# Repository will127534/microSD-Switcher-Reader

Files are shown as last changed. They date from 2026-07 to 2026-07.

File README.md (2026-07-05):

# microSD-Switcher-Reader: A simple USB3.0 uSD card reader with a SD card switch for SBCs
_DSC1927

## Introduction
Basically I want some hardware that I can have agents to load images on RPI and test it all from software cmd to have it build/test RPI images for me. There has been some design out there but most of them are USB2.0 which is kinda slow so I wanna build one using USB3 SD reader, and additionally because I'm targeting RPI here, I also whould like to have USB to UART along with a GPIO to power switch on and off the RPI5.

_DSC1934
_DSC1929

So I have the board with GL3224 (USB3 SD card reader) and MCP2221A (USB2 to GPIO/UART/I2C), and because USB3 connector has both USB3 and USB2 signal, I have it connected to the two ICs so no USB hub needed for the two.

The board has been tested with RPI5 and GL3224 has been tested with 100 Megabytes/sec read/write speed. 

Also thanks to https://github.com/NVNTLabs/switch2-SDEX2M2 from NVNTLabs for the microSD card PCB library. (It is a neet MicroSD Express to M.2 adaptor board for Switch2)

## Notes
* Gerber and CPL and BOM file for JLCPCB is under /Gerber
* [Interactive BOM](https://htmlpreview.github.io/?https://github.com/will127534/microSD-Switcher-Reader/blob/main/bom/ibom.html) [(provided by InteractiveHtmlBom)](https://github.com/openscopeproject/InteractiveHtmlBom)   
* Source Code for MCP2221A under /software

## Support
For questions, issues, or suggestions, please open an issue in the [GitHub repository](https://github.com/will127534/microSD-Switcher-Reader/issues)

## Schematic


## PCB


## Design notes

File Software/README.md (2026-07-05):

# SD Switcher Rig

This workspace contains two related tools for a Raspberry Pi SD-switching fixture.

## Tool Overview

`mcp2221_switch.py`

- direct MCP2221 GPIO control
- `GP2`: SD route
  - high: SD connected to the host SD card reader
  - low: SD connected to the target device
- `GP3`: target power/reset switch
  - high for `0.1 s`: short press to boot
  - high for `5.0 s`: long press to hard power off
- `GP0` and `GP1`: left in their current UART LED alternate modes

`initialization.py`

- initialize the MCP2221 to have the default state switch to SD read

## Quick Start

Show live MCP2221 state:

```bash
sudo /home/pi/sd_switcher/mcp2221_switch.py status
```

Route SD to the target device:

```bash
sudo /home/pi/sd_switcher/mcp2221_switch.py sd device
```

Route SD to the host SD card reader:

```bash
sudo /home/pi/sd_switcher/mcp2221_switch.py sd reader
```

Pulse the reset output high for 100 ms:

```bash
sudo /home/pi/sd_switcher/mcp2221_switch.py reset
```

List visible HID devices:

```bash
sudo /home/pi/sd_switcher/mcp2221_switch.py list
```

## Main Files

- `mcp2221_switch.py`: low-level MCP2221 HID controller
- `initialization.py`: programs persistent MCP2221 flash defaults for GP0-GP3

## Persistent MCP2221 Defaults

Program the MCP2221 flash defaults for this fixture:

```bash
sudo /home/pi/sd_switcher/initialization.py apply
```

This sets:

- `GP2` power-up default to GPIO output high
- `GP3` power-up default to GPIO output low
- `GP0` to `LED_URX`
- `GP1` to `LED_UTX`
- UART RX/TX LED polarity to inactive-low / active-high in flash

Inspect the current flash and SRAM GP settings:

```bash
sudo /home/pi/sd_switcher/initialization.py status
```

Reset the MCP2221 so flash chip settings reload:

```bash
sudo /home/pi/sd_switcher/initialization.py reset
```

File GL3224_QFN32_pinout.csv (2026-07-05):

AVDD12 3
AVDD33 8
AVDD33 30
DVDD12 17
DVDD33 16
DVDD33 25
VBUS 15 P
VUHSI 24
SD_VCC 26
GND 27
DP 32
DM 31
TXN 1
TXP 2
RXN 4
RXP 5
RTERM 9
X1 6
X2 7
SD_WP 28
SD_CDZ 29
SD_D1 18
SD_D0 19
SD_CK 20
SD_CM 21
SD_D3 22
SD_D2 23
LED 14
SPI_CS 13
SPI_CK 12
SPI_MISO 10
SPI_MOSI 11

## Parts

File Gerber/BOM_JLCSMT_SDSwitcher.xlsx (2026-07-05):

Comment | Designator | Footprint | JLCPCB Part #（optional）
100nF | C1,C8,C14,C10,C22,C12,C26,C17,C21,C4,C11,C13,C9,C6,C25,C15,C7,C16,C24,C5,C20 | C_0402_1005Metric | C307331
Crystal_CL | C2,C3 | C_0402_1005Metric | C32949
1uF | C19,C18 | C_0402_1005Metric | C52923
25Mhz | Y1 | Crystal_SMD_2520-4Pin_2.5x2.0mm | C7420789
TMUX1574DYYR | U1,U7 | DYY0016A_TEX | C1855769
HD3SS3220IRNHR | IC1 | HD3SS3220IRNHR | C701817
Conn_01x03_MountingPin | J4 | JST_SH_SM03B-SRSS-TB_1x03-1MP_P1.00mm_Horizontal | C160403
Conn_01x04_Shielded | J1 | JST_SH_SM04B-SRSS-TB_1x04-1MP_P1.00mm_Horizontal | C160404
Green | D2,D4 | LED_0603_1608Metric | C12624
Red | D3,D1 | LED_0603_1608Metric | C2286
Blue | D6 | LED_0603_1608Metric | C2288
Orange | D5 | LED_0603_1608Metric | C2287
DM3D-SF | J3 | DM3D-SF | C719027
Conn_01x02_MountingPin | J6 | Molex_PicoBlade_53261-0271_1x02-1MP_P1.25mm_Horizontal | C177225
MCP2221AxML | U2 | QFN-16-1EP_4x4mm_P0.65mm_EP2.5x2.5mm | C637689
GL3224 | U3 | QFN-32-1EP_5x5mm_P0.5mm_EP3.1x3.1mm | C157357
10K | R16,R8,R1,R12,R11,R13,R17 | R_0402_1005Metric | C25744
1K | R4,R18,R3 | R_0402_1005Metric | C11702
900K | R14 | R_0402_1005Metric | C25799
470R | R19,R10,R7,R2,R9,R6 | R_0402_1005Metric | C25117
680R | R5 | R_0402_1005Metric | C25130
200K | R15 | R_0402_1005Metric | C25764
25CSM04xxSN | U4 | SOIC-8_3.9x4.9mm_P1.27mm | C2928893
BSS214NW | Q4,Q3,Q5,Q1,Q2 | SOT-323_SC-70 | C3247496
SiP32431DR3 | U9,U5 | SOT-363_SC-70-6 | C141606
USB_C_Receptacle | J5 | USB_C_Receptacle_Amphenol_12401610E4-2A | C5119948
LP5912-3.3DRV | U6 | WSON-6-1EP_2x2mm_P0.65mm_EP1x1.6mm_ThermalVias | C134121

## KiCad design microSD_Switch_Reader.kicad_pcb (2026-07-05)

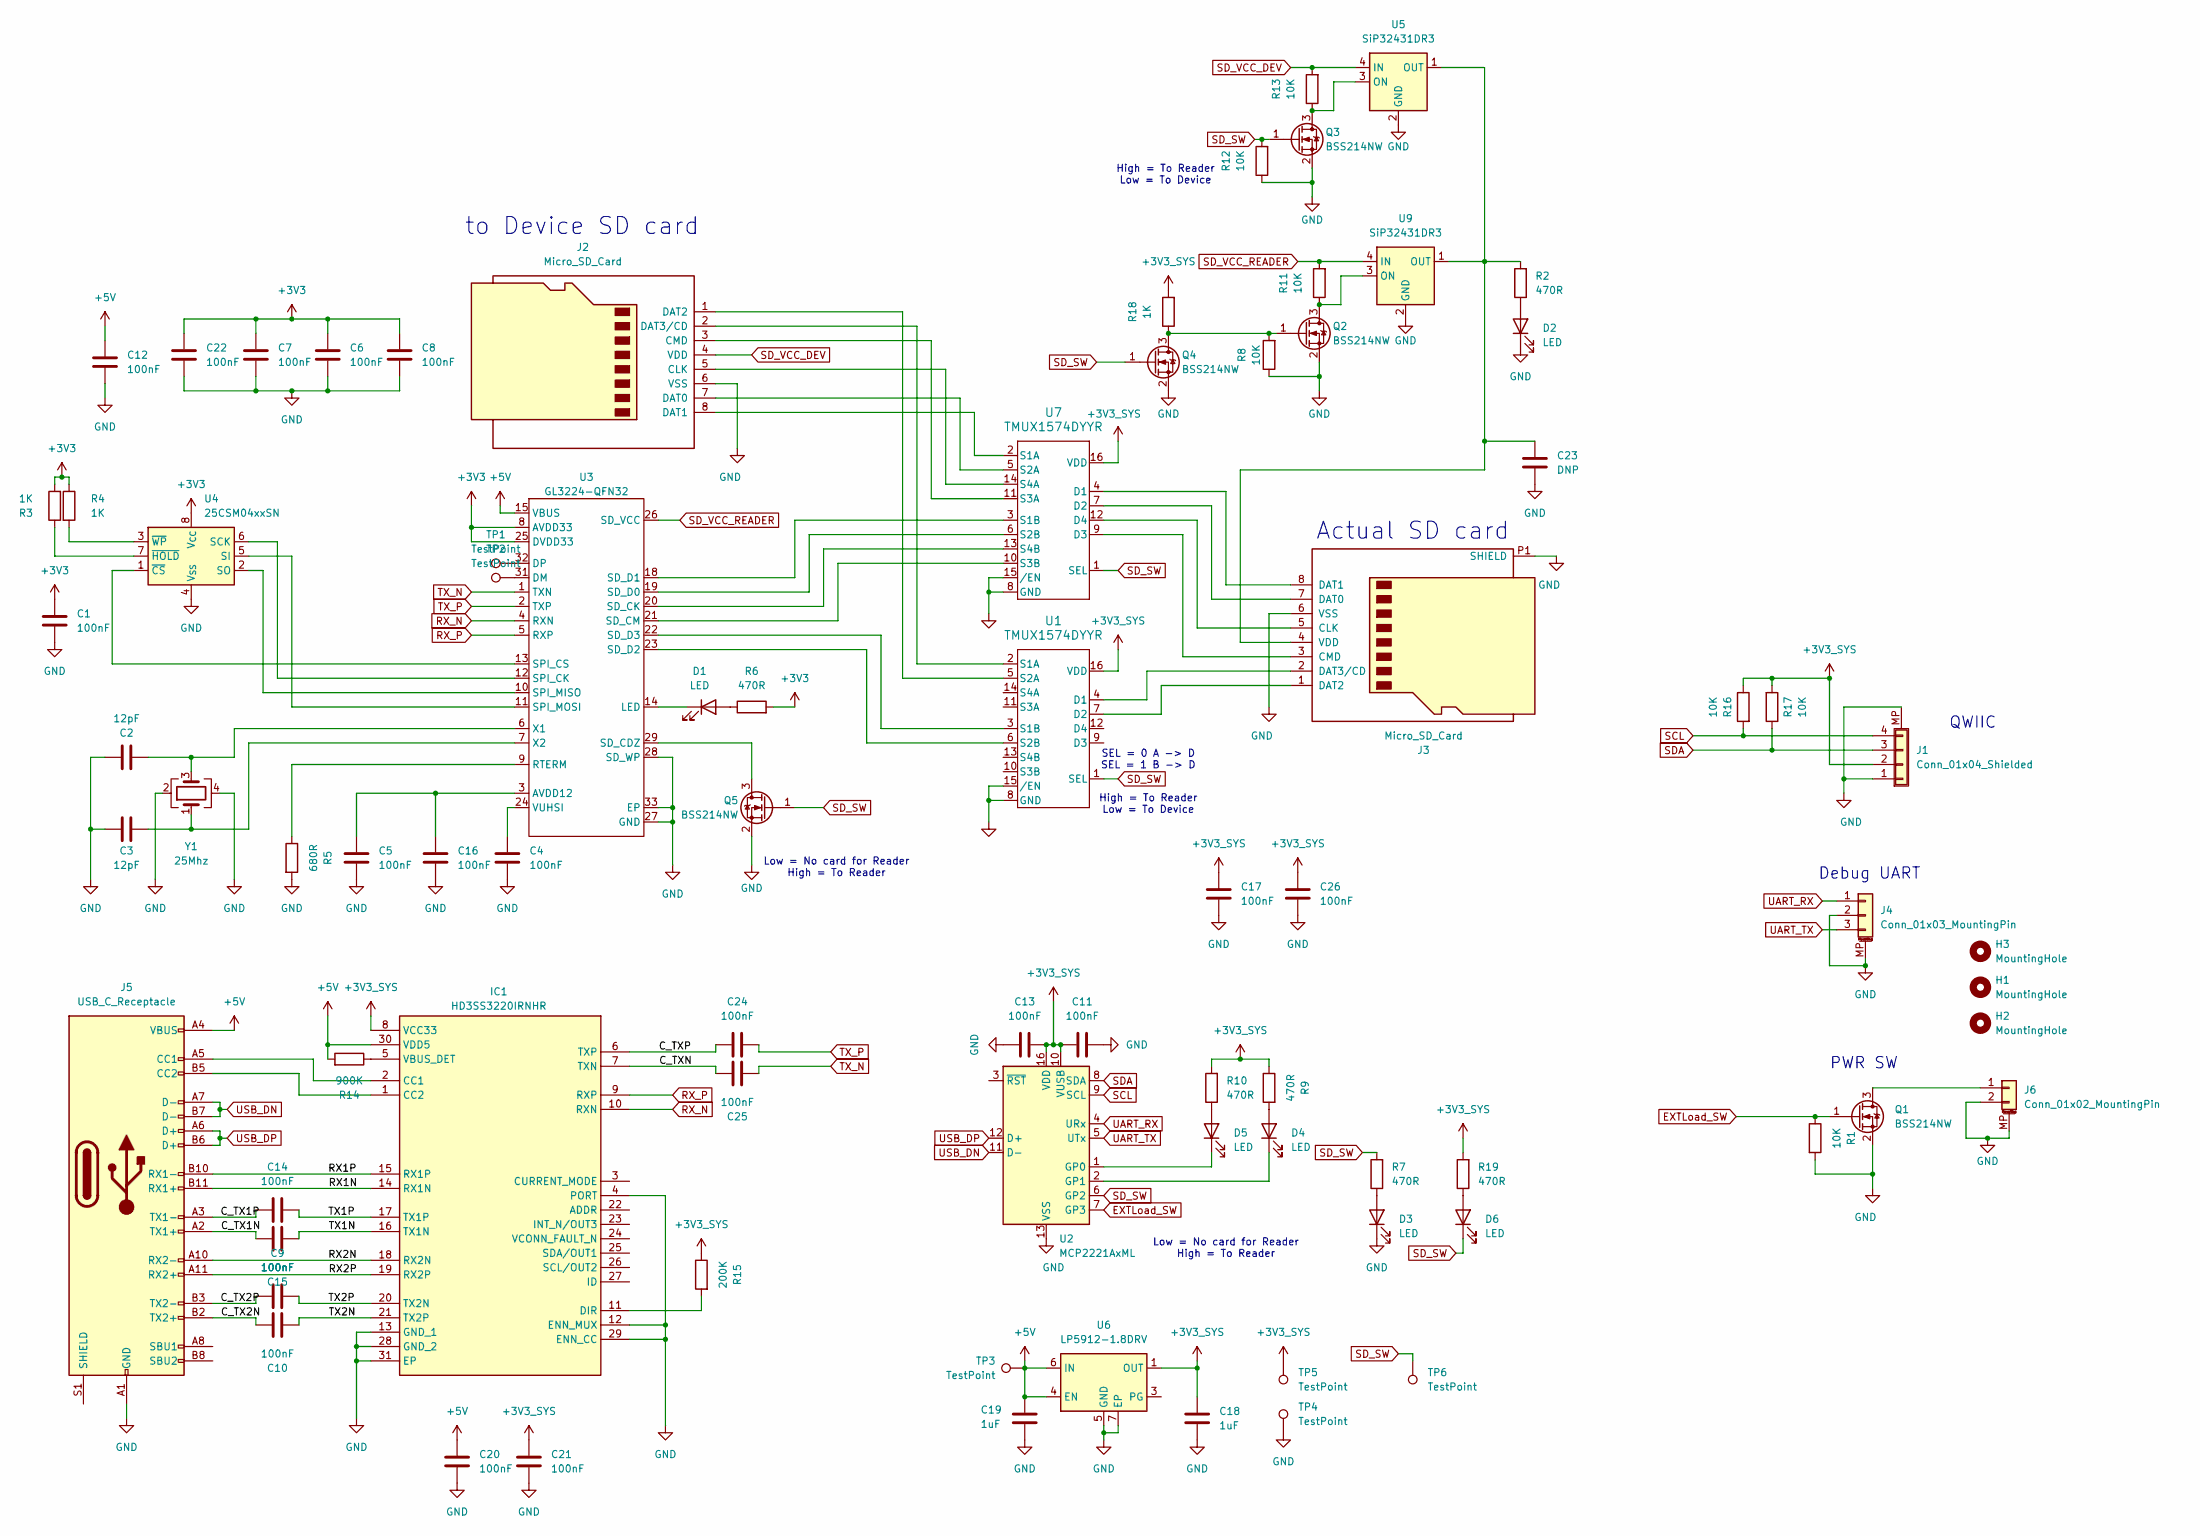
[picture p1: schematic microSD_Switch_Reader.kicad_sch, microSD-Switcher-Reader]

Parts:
C1, C4, C5, C6, C7, C8, C9, C10, C11, C12, C13, C14, C15, C16, C17, C20, C21, C22, C24, C25, C26: 100nF; C_0402_1005Metric
C2, C3: 12pF; C_0402_1005Metric
C18, C19: 1uF; C_0402_1005Metric
C23: DNP; C_0603_1608Metric
D1, D2, D3, D4, D5, D6: LED; LED_0603_1608Metric
H1, H2, H3: MountingHole; MountingHole_2.2mm_M2
IC1: HD3SS3220IRNHR; Mouser Part Number 595-HD3SS3220IRNHR
J1: Conn_01x04_Shielded; JST_SH_SM04B-SRSS-TB_1x04-1MP_P1.00mm_Horizontal
J2: Micro_SD_Card; usdex-male-open_bottom
J3: Micro_SD_Card; microSD_HC_Hirose_DM3D-SF
J4: Conn_01x03_MountingPin; JST_SH_SM03B-SRSS-TB_1x03-1MP_P1.00mm_Horizontal
J5: USB_C_Receptacle; USB_C_Receptacle_Amphenol_12401610E4-2A
J6: Conn_01x02_MountingPin; Molex_PicoBlade_53261-0271_1x02-1MP_P1.25mm_Horizontal
Q1, Q2, Q3, Q4, Q5: BSS214NW; SOT-323_SC-70
R1, R8, R11, R12, R13, R16, R17: 10K; R_0402_1005Metric
R2, R6, R7, R9, R10, R19: 470R; R_0402_1005Metric
R3, R4, R18: 1K; R_0402_1005Metric
R5: 680R; R_0402_1005Metric
R14: 900K; R_0402_1005Metric
R15: 200K; R_0402_1005Metric
TP1, TP2, TP3, TP4, TP5, TP6: TestPoint; TestPoint_Pad_D1.0mm
U1, U7: TMUX1574DYYR; DYY0016A_TEX
U2: MCP2221AxML; QFN-16-1EP_4x4mm_P0.65mm_EP2.5x2.5mm
U3: GL3224-QFN32; QFN-32-1EP_5x5mm_P0.5mm_EP3.1x3.1mm
U4: 25CSM04xxSN; SOIC-8_3.9x4.9mm_P1.27mm
U5, U9: SiP32431DR3; SOT-363_SC-70-6
U6: LP5912-1.8DRV; WSON-6-1EP_2x2mm_P0.65mm_EP1x1.6mm_ThermalVias
Y1: 25Mhz; Crystal_SMD_2520-4Pin_2.5x2.0mm

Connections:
+3V3: C1.1, C6.1, C7.1, C8.1, C22.1, R3.2, R4.1, R6.2, U3.8 (AVDD33), U3.16 (DVDD33), U3.25 (DVDD33), U3.30 (AVDD33), U4.8 (V_{CC})
+3V3_SYS: C11.1, C13.2, C17.1, C18.1, C21.1, C26.1, IC1.8 (VCC33), J1.2, R9.1, R10.2, R15.1, R16.1, R17.2, R18.2, R19.2, TP5.1, U1.16 (VDD), U2.10 (VUSB), U2.16 (VDD), U6.1 (OUT), U7.16 (VDD)
+5V: C12.1, C19.1, C20.1, IC1.30 (VDD5), J5.A4 (VBUS), J5.A9 (VBUS), J5.B4 (VBUS), J5.B9 (VBUS), R14.2, TP3.1, U3.15 (VBUS), U6.4 (EN), U6.6 (IN)
/C_TX1N: C15.2, J5.A2 (TX1+)
/C_TX1P: C14.1, J5.A3 (TX1-)
/C_TX2N: C10.2, J5.B2 (TX2+)
/C_TX2P: C9.1, J5.B3 (TX2-)
/C_TXN: C25.2, IC1.7 (TXN)
/C_TXP: C24.1, IC1.6 (TXP)
/RX1N: IC1.14 (RX1N), J5.B11 (RX1+)
/RX1P: IC1.15 (RX1P), J5.B10 (RX1-)
/RX2N: IC1.18 (RX2N), J5.A10 (RX2-)
/RX2P: IC1.19 (RX2P), J5.A11 (RX2+)
/TX1N: C15.1, IC1.16 (TX1N)
/TX1P: C14.2, IC1.17 (TX1P)
/TX2N: C10.1, IC1.21 (TX2P)
/TX2P: C9.2, IC1.20 (TX2N)
EXTLoad_SW: Q1.1 (G), R1.1, U2.7 (GP3)
GND: C1.2, C2.1, C3.1, C4.2, C5.2, C6.2, C7.2, C8.2, C11.2, C12.2, C13.1, C16.2, C17.2, C18.2, C19.2, C20.2, C21.2, C22.2, C23.2, C26.2, D2.1 (K), D3.1 (K), IC1.4 (PORT), IC1.12 (ENN_MUX), IC1.13 (GND_1), IC1.28 (GND_2), IC1.29 (ENN_CC), IC1.31 (EP), J1.1, J1.MP (Shield), J2.6 (VSS), J3.6 (VSS), J3.P1 (SHIELD), J3.P2 (SHIELD), J3.P3 (SHIELD), J3.P4 (SHIELD), J3.P5 (SHIELD), J4.2, J4.MP (MountPin), J5.A1 (GND), J5.A12 (GND), J5.B1 (GND), J5.B12 (GND), J6.2, J6.MP (MountPin), Q1.2 (S), Q2.2 (S), Q3.2 (S), Q4.2 (S), Q5.2 (S), R1.2, R5.2, R8.1, R12.1, TP4.1, U1.8 (GND), U1.15 (/EN), U2.13 (VSS), U3.27 (GND), U3.28 (SD_WP), U3.33 (EP), U4.4 (V_{SS}), U5.2 (GND), U5.5 (GND), U6.5 (GND), U6.7 (EP), U7.8 (GND), U7.15 (/EN), U9.2 (GND), U9.5 (GND), Y1.2, Y1.4
unnamed: D1.2 (A), R6.1
unnamed: D1.1 (K), U3.14 (LED)
unnamed: D2.2 (A), R2.1
unnamed: D3.2 (A), R7.1
unnamed: D4.2 (A), R9.2
unnamed: D4.1 (K), U2.2 (GP1)
unnamed: D5.2 (A), R10.1
unnamed: D5.1 (K), U2.1 (GP0)
unnamed: D6.2 (A), R19.1
unnamed: IC1.2 (CC1), J5.A5 (CC1)
unnamed: IC1.1 (CC2), J5.B5 (CC2)
unnamed: IC1.11 (DIR), R15.2
unnamed: IC1.5 (VBUS_DET), R14.1
unnamed: J2.5 (CLK), U7.14 (S4A)
unnamed: J2.3 (CMD), U7.11 (S3A)
unnamed: J2.7 (DAT0), U7.5 (S2A)
unnamed: J2.8 (DAT1), U7.2 (S1A)
unnamed: J2.1 (DAT2), U1.5 (S2A)
unnamed: J2.2 (DAT3/CD), U1.2 (S1A)
unnamed: J3.5 (CLK), U7.12 (D4)
unnamed: J3.3 (CMD), U7.9 (D3)
unnamed: J3.7 (DAT0), U7.7 (D2)
unnamed: J3.8 (DAT1), U7.4 (D1)
unnamed: J3.1 (DAT2), U1.7 (D2)
unnamed: J3.2 (DAT3/CD), U1.4 (D1)
unnamed: C23.1, J3.4 (VDD), R2.2, U5.1 (OUT), U9.1 (OUT)
unnamed: J6.1, Q1.3 (D)
unnamed: Q2.3 (D), R11.1, U9.3 (ON)
unnamed: Q2.1 (G), Q4.3 (D), R8.2, R18.1
unnamed: Q3.3 (D), R13.1, U5.3 (ON)
unnamed: Q5.3 (D), U3.29 (SD_CDZ)
unnamed: U1.3 (S1B), U3.22 (SD_D3)
unnamed: U1.6 (S2B), U3.23 (SD_D2)
unnamed: C5.1, C16.1, U3.3 (AVDD12), U3.17 (DVDD12)
unnamed: TP2.1, U3.31 (DM)
unnamed: TP1.1, U3.32 (DP)
unnamed: R5.1, U3.9 (RTERM)
unnamed: U3.20 (SD_CK), U7.13 (S4B)
unnamed: U3.21 (SD_CM), U7.10 (S3B)
unnamed: U3.19 (SD_D0), U7.6 (S2B)
unnamed: U3.18 (SD_D1), U7.3 (S1B)
unnamed: U3.12 (SPI_CK), U4.6 (SCK)
unnamed: U3.13 (SPI_CS), U4.1 (~CS)
unnamed: U3.10 (SPI_MISO), U4.2 (SO)
unnamed: U3.11 (SPI_MOSI), U4.5 (SI)
unnamed: C4.1, U3.24 (VUHSI)
unnamed: C2.2, U3.6 (X1), Y1.3
unnamed: C3.2, U3.7 (X2), Y1.1
unnamed: R3.1, U4.7 (~HOLD)
unnamed: R4.2, U4.3 (~WP)
RX_N: IC1.10 (RXN), U3.4 (RXN)
RX_P: IC1.9 (RXP), U3.5 (RXP)
SCL: J1.4, R16.2, U2.9 (SCL)
SDA: J1.3, R17.1, U2.8 (SDA)
SD_SW: D6.1 (K), Q3.1 (G), Q4.1 (G), Q5.1 (G), R7.2, R12.2, TP6.1, U1.1 (SEL), U2.6 (GP2), U7.1 (SEL)
SD_VCC_DEV: J2.4 (VDD), R13.2, U5.4 (IN)
SD_VCC_READER: R11.2, U3.26 (SD_VCC), U9.4 (IN)
TX_N: C25.1, U3.1 (TXN)
TX_P: C24.2, U3.2 (TXP)
UART_RX: J4.1, U2.4 (URx)
UART_TX: J4.3, U2.5 (UTx)
USB_DN: J5.A7 (D-), J5.B7 (D-), U2.11 (D-)
USB_DP: J5.A6 (D+), J5.B6 (D+), U2.12 (D+)

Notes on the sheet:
High = To Reader Low = To Device
Low = No card for Reader High = To Reader
SEL = 0 A -> D SEL = 1 B -> D
QWIIC
to Device SD card
PWR SW
Actual SD card
Debug UART

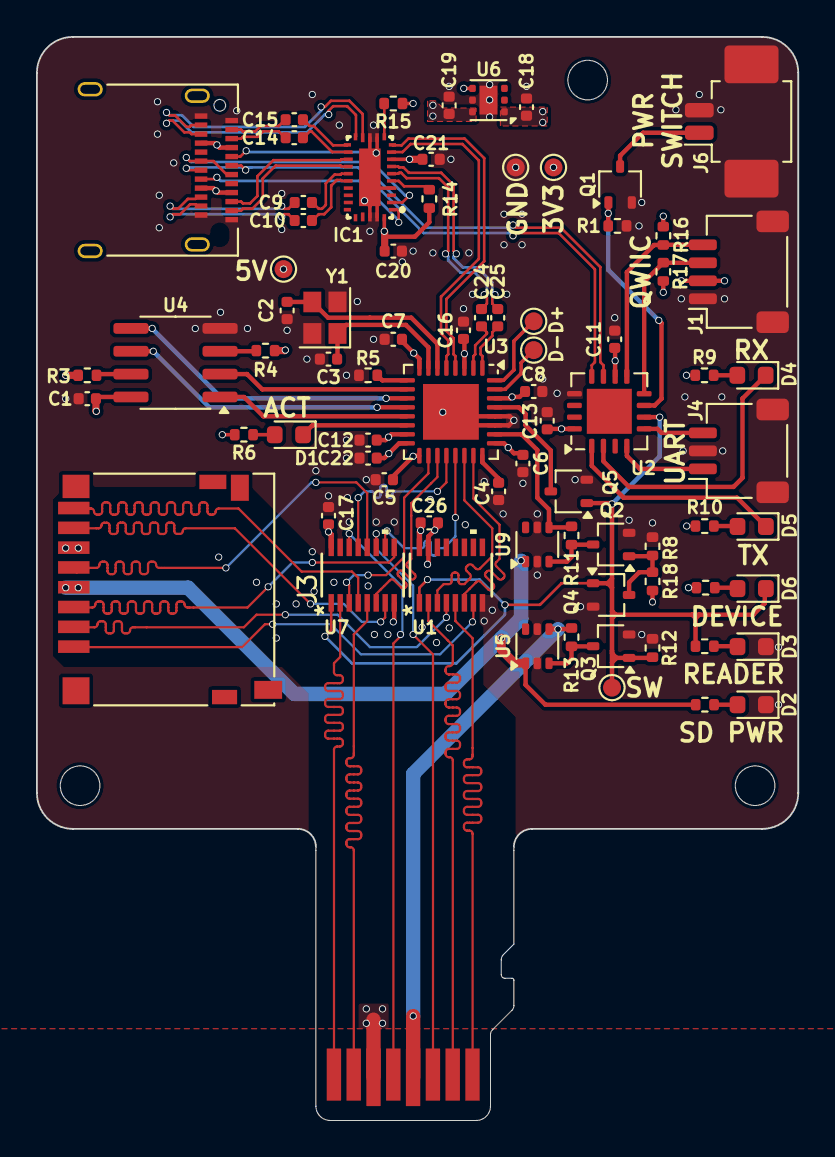
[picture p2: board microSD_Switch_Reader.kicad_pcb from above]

Board: 4 copper layers, 42.3 x 60.2 mm, 81 parts (1 on the bottom side), 82 nets.

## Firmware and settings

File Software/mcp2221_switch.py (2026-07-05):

#!/usr/bin/env python3
"""Control GP2/GP3 switches on a Microchip MCP2221/MCP2221A."""

from __future__ import annotations

import argparse
import ctypes
import ctypes.util
import sys
import time
from dataclasses import dataclass


REPORT_SIZE = 64
WRITE_REPORT_SIZE = REPORT_SIZE + 1

CMD_SET_GPIO_OUTPUT_VALUES = 0x50
CMD_GET_GPIO_VALUES = 0x51
CMD_SET_SRAM_SETTINGS = 0x60
CMD_GET_SRAM_SETTINGS = 0x61
CMD_RESET_CHIP = 0x70
CMD_READ_FLASH_DATA = 0xB0
CMD_WRITE_FLASH_DATA = 0xB1

GPIO_DIRECTION_OUTPUT = 0
GPIO_DIRECTION_INPUT = 1
GPIO_DESIGNATION_GPIO = 0
GPIO_DESIGNATION_DEDICATED = 1
GPIO_DESIGNATION_ALT0 = 2
GPIO_DESIGNATION_ALT1 = 3
GPIO_DESIGNATION_ALT2 = 4

PIN_UART_RX_LED = 0
PIN_UART_TX_LED = 1
PIN_SD_SWITCH = 2
PIN_RESET_SWITCH = 3

SD_ROUTE_DEVICE = False
SD_ROUTE_READER = True


class MCP2221Error(RuntimeError):
    """Raised when MCP2221 communication or configuration fails."""


@dataclass(frozen=True)
class DeviceInfo:
    path: str
    vendor_id: int
    product_id: int
    serial_number: str
    manufacturer_string: str
    product_string: str
    interface_number: int


def state_text(value: bool) -> str:
    return "on" if value else "off"


def level_text(value: bool) -> str:
    return "high" if value else "low"


def sd_route_text(value: bool) -> str:
    return "reader (high)" if value else "device (low)"


def parse_hex_int(value: str) -> int:
    return int(value, 0)


class HidDeviceInfo(ctypes.Structure):
    pass


HidDeviceInfoPtr = ctypes.POINTER(HidDeviceInfo)
HidDeviceInfo._fields_ = [
    ("path", ctypes.c_char_p),
    ("vendor_id", ctypes.c_ushort),
    ("product_id", ctypes.c_ushort),
    ("serial_number", ctypes.c_wchar_p),
    ("release_number", ctypes.c_ushort),
    ("manufacturer_string", ctypes.c_wchar_p),
    ("product_string", ctypes.c_wchar_p),
    ("usage_page", ctypes.c_ushort),
    ("usage", ctypes.c_ushort),
    ("interface_number", ctypes.c_int),
    ("next", HidDeviceInfoPtr),
    ("bus_type", ctypes.c_int),
]


class HidApi:
    def __init__(self) -> None:
        library_name = (
            ctypes.util.find_library("hidapi-hidraw")
            or ctypes.util.find_library("hidapi-libusb")
            or "libhidapi-hidraw.so.0"
        )
        self.lib = ctypes.CDLL(library_name)

        self.lib.hid_init.argtypes = []
        self.lib.hid_init.restype = ctypes.c_int

        self.lib.hid_exit.argtypes = []
        self.lib.hid_exit.restype = ctypes.c_int

        self.lib.hid_error.argtypes = [ctypes.c_void_p]
        self.lib.hid_error.restype = ctypes.c_wchar_p

        self.lib.hid_enumerate.argtypes = [ctypes.c_ushort, ctypes.c_ushort]
        self.lib.hid_enumerate.restype = HidDeviceInfoPtr

        self.lib.hid_free_enumeration.argtypes = [HidDeviceInfoPtr]
        self.lib.hid_free_enumeration.restype = None

        self.lib.hid_open_path.argtypes = [ctypes.c_char_p]
        self.lib.hid_open_path.restype = ctypes.c_void_p

        self.lib.hid_close.argtypes = [ctypes.c_void_p]
        self.lib.hid_close.restype = None

        self.lib.hid_write.argtypes = [
            ctypes.c_void_p,
            ctypes.POINTER(ctypes.c_ubyte),
            ctypes.c_size_t,
        ]
        self.lib.hid_write.restype = ctypes.c_int

        self.lib.hid_read_timeout.argtypes = [
            ctypes.c_void_p,
            ctypes.POINTER(ctypes.c_ubyte),
            ctypes.c_size_t,
            ctypes.c_int,
        ]
        self.lib.hid_read_timeout.restype = ctypes.c_int

        self.lib.hid_set_nonblocking.argtypes = [ctypes.c_void_p, ctypes.c_int]
        self.lib.hid_set_nonblocking.restype = ctypes.c_int

        if self.lib.hid_init() != 0:
            raise MCP2221Error("hidapi initialization failed")

    def close(self) -> None:
        self.lib.hid_exit()

    def error_text(self, handle: ctypes.c_void_p | None = None) -> str:
        text = self.lib.hid_error(handle)
        return text or "unknown hidapi error"

    def enumerate(self) -> list[DeviceInfo]:
        devices: list[DeviceInfo] = []
        head = self.lib.hid_enumerate(0, 0)
        current = head
        try:
            while current:
                entry = current.contents
                devices.append(
                    DeviceInfo(
                        path=(entry.path or b"").decode("utf-8", errors="replace"),
                        vendor_id=entry.vendor_id,
                        product_id=entry.product_id,
                        serial_number=entry.serial_number or "",
                        manufacturer_string=entry.manufacturer_string or "",
                        product_string=entry.product_string or "",
                        interface_number=entry.interface_number,
                    )
                )
                current = entry.next
        finally:
            if head:
                self.lib.hid_free_enumeration(head)
        return devices

    def open_path(self, path: str) -> ctypes.c_void_p:
        handle = self.lib.hid_open_path(path.encode("utf-8"))
        if not handle:
            raise MCP2221Error(f"failed to open {path}: {self.error_text(None)}")
        if self.lib.hid_set_nonblocking(handle, 0) != 0:
            error = self.error_text(handle)
            self.lib.hid_close(handle)
            raise MCP2221Error(f"failed to configure blocking I/O: {error}")
        return handle


def describe_pin_mode(setting: int) -> str:
    designation = setting & 0x07
    direction = (setting >> 3) & 0x01
    output_value = (setting >> 4) & 0x01

    if designation == GPIO_DESIGNATION_GPIO:
        if direction == GPIO_DIRECTION_OUTPUT:
            return f"gpio-output ({state_text(bool(output_value))})"
        return "gpio-input"

    if designation == GPIO_DESIGNATION_DEDICATED:
        return "dedicated"

    if designation == GPIO_DESIGNATION_ALT0:
        return "alternate-0"

    if designation == GPIO_DESIGNATION_ALT1:
        return "alternate-1"

    if designation == GPIO_DESIGNATION_ALT2:
        return "alternate-2"

    return f"reserved ({designation})"


def encode_pin_setting(designation: int, direction: int, output_value: bool) -> int:
    return (designation & 0x07) | ((direction & 0x01) << 3) | (int(output_value) << 4)


class MCP2221:
    def __init__(self, hidapi: HidApi, path: str, timeout_ms: int = 1000) -> None:
        self.hidapi = hidapi
        self.handle = hidapi.open_path(path)
        self.timeout_ms = timeout_ms

    def close(self) -> None:
        if self.handle:
            self.hidapi.lib.hid_close(self.handle)
            self.handle = None

    def __enter__(self) -> "MCP2221":
        return self

    def __exit__(self, exc_type, exc, tb) -> None:
        self.close()

    def transact(
        self,
        payload: bytes,
        expect_response: bool = True,
        expected_command: int | None = None,
    ) -> bytes:
        if len(payload) != REPORT_SIZE:
            raise ValueError("MCP2221 reports must be exactly 64 bytes")

        outgoing = (ctypes.c_ubyte * WRITE_REPORT_SIZE)()
        outgoing[0] = 0
        for index, value in enumerate(payload, start=1):
            outgoing[index] = value

        written = self.hidapi.lib.hid_write(self.handle, outgoing, WRITE_REPORT_SIZE)
        if written < 0:
            raise MCP2221Error(f"hid_write failed: {self.hidapi.error_text(self.handle)}")

        if not expect_response:
            return b""

        # The MCP2221 can leave a previous command response queued briefly across
        # rapid reconnects/open-close cycles. Read until the expected response
        # arrives so follow-up sessions do not fail on a stale packet.
        for _ in range(4):
            incoming = (ctypes.c_ubyte * REPORT_SIZE)()
            received = self.hidapi.lib.hid_read_timeout(
                self.handle, incoming, REPORT_SIZE, self.timeout_ms
            )
            if received < 0:
                raise MCP2221Error(
                    f"hid_read_timeout failed: {self.hidapi.error_text(self.handle)}"
                )
            if received == 0:
                raise MCP2221Error("timed out waiting for MCP2221 response")

            reply = bytes(incoming[:received])
            if len(reply) < REPORT_SIZE:
                reply += bytes(REPORT_SIZE - len(reply))

            if expected_command is None or reply[0] == expected_command:
                return reply

        raise MCP2221Error(
            f"timed out waiting for command 0x{expected_command:02x} response"
        )

    def get_sram_settings(self) -> bytes:
        request = bytearray(REPORT_SIZE)
        request[0] = CMD_GET_SRAM_SETTINGS
        response = self.transact(bytes(request), expected_command=CMD_GET_SRAM_SETTINGS)
        if response[0] != CMD_GET_SRAM_SETTINGS or response[1] != 0x00:
            raise MCP2221Error(f"unexpected Get SRAM Settings response: {response[:8].hex()}")
        return response

    def reset_chip(self) -> None:
        request = bytearray(REPORT_SIZE)
        request[0] = CMD_RESET_CHIP
        request[1] = 0xAB
        request[2] = 0xCD
        request[3] = 0xEF
        self.transact(bytes(request), expect_response=False)

    def get_flash_chip_settings(self) -> bytes:
        request = bytearray(REPORT_SIZE)
        request[0] = CMD_READ_FLASH_DATA
        request[1] = 0x00
        response = self.transact(bytes(request), expected_command=CMD_READ_FLASH_DATA)
        if response[0] != CMD_READ_FLASH_DATA or response[1] != 0x00:
            raise MCP2221Error(f"unexpected Read Flash Data response: {response[:8].hex()}")
        if response[2] < 4:
            raise MCP2221Error(f"invalid chip settings length in flash response: {response[2]}")
        return response[4:8]

    def get_flash_gpio_settings(self) -> bytes:
        request = bytearray(REPORT_SIZE)
        request[0] = CMD_READ_FLASH_DATA
        request[1] = 0x01
        response = self.transact(bytes(request), expected_command=CMD_READ_FLASH_DATA)
        if response[0] != CMD_READ_FLASH_DATA or response[1] != 0x00:
            raise MCP2221Error(f"unexpected Read Flash Data response: {response[:8].hex()}")
        if response[2] < 4:
            raise MCP2221Error(f"invalid GP settings length in flash response: {response[2]}")
        return response[4:8]

    def get_gpio_values(self) -> bytes:
        request = bytearray(REPORT_SIZE)
        request[0] = CMD_GET_GPIO_VALUES
        response = self.transact(bytes(request), expected_command=CMD_GET_GPIO_VALUES)
        if response[0] != CMD_GET_GPIO_VALUES or response[1] != 0x00:
            raise MCP2221Error(f"unexpected Get GPIO Values response: {response[:8].hex()}")
        return response

    def set_sram_gpio_settings(self, gp_settings: list[int]) -> None:
        if len(gp_settings) != 4:
            raise ValueError("expected four GP settings bytes")

        request = bytearray(REPORT_SIZE)
        request[0] = CMD_SET_SRAM_SETTINGS
        request[7] = 0x80
        request[8:12] = bytes(gp_settings)

        response = self.transact(bytes(request), expected_command=CMD_SET_SRAM_SETTINGS)
        if response[0] != CMD_SET_SRAM_SETTINGS or response[1] != 0x00:
            raise MCP2221Error(f"failed to update SRAM GPIO settings: {response[:8].hex()}")

    def set_flash_gpio_settings(self, gp_settings: list[int]) -> None:
        if len(gp_settings) != 4:
            raise ValueError("expected four GP settings bytes")

        request = bytearray(REPORT_SIZE)
        request[0] = CMD_WRITE_FLASH_DATA
        request[1] = 0x01
        request[2:6] = bytes(gp_settings)

        response = self.transact(bytes(request), expected_command=CMD_WRITE_FLASH_DATA)
        if response[0] != CMD_WRITE_FLASH_DATA:
            raise MCP2221Error(f"unexpected Write Flash Data response: {response[:8].hex()}")
        if response[1] == 0x00:
            return
        if response[1] == 0x02:
            raise MCP2221Error("flash write command is not supported by this device")
        if response[1] == 0x03:
            raise MCP2221Error("flash write command was rejected by the device")
        raise MCP2221Error(f"failed to update flash GPIO settings: {response[:8].hex()}")

    def set_flash_chip_settings(self, chip_settings: list[int]) -> None:
        if len(chip_settings) != 4:
            raise ValueError("expected four chip settings bytes")

        request = bytearray(REPORT_SIZE)
        request[0] = CMD_WRITE_FLASH_DATA
        request[1] = 0x00
        request[2:6] = bytes(chip_settings)

        response = self.transact(bytes(request), expected_command=CMD_WRITE_FLASH_DATA)
        if response[0] != CMD_WRITE_FLASH_DATA:
            raise MCP2221Error(f"unexpected Write Flash Data response: {response[:8].hex()}")
        if response[1] == 0x00:
            return
        if response[1] == 0x02:
            raise MCP2221Error("flash write command is not supported by this device")
        if response[1] == 0x03:
            raise MCP2221Error("flash write command was rejected by the device")
        raise MCP2221Error(f"failed to update flash chip settings: {response[:8].hex()}")

    def set_gpio_outputs(self, states: dict[int, bool]) -> None:
        request = bytearray(REPORT_SIZE)
        request[0] = CMD_SET_GPIO_OUTPUT_VALUES

        for pin, state in states.items():
            base = 2 + (pin * 4)
            request[base] = 0x01
            request[base + 1] = 0x01 if state else 0x00
            request[base + 2] = 0x01
            request[base + 3] = 0x00

        response = self.transact(bytes(request), expected_command=CMD_SET_GPIO_OUTPUT_VALUES)
        if response[0] != CMD_SET_GPIO_OUTPUT_VALUES or response[1] != 0x00:
            raise MCP2221Error(f"failed to set GPIO outputs: {response[:8].hex()}")

        for pin in states:
            base = 2 + (pin * 4)
            if 0xEE in response[base : base + 4]:
                raise MCP2221Error(
                    f"GP{pin} is not configured for GPIO operation; runtime configuration failed"
                )

    def pin_setting(self, sram: bytes, pin: int) -> int:
        return sram[22 + pin]

    def ensure_pin_outputs(self, requested_states: dict[int, bool]) -> dict[int, bool]:
        sram = self.get_sram_settings()

        gp_settings = [
            self.pin_setting(sram, 0),
            self.pin_setting(sram, 1),
            self.pin_setting(sram, 2),
            self.pin_setting(sram, 3),
        ]

        if not requested_states:
            raise MCP2221Error("no GPIO state requested")

        target_states: dict[int, bool] = {}
        for pin, requested_state in requested_states.items():
            current_setting = gp_settings[pin]
            is_gpio_output = (current_setting & 0x0F) == 0x00

            target_states[pin] = requested_state

            if not is_gpio_output:
                gp_settings[pin] = (
                    GPIO_DESIGNATION_GPIO
                    | (GPIO_DIRECTION_OUTPUT << 3)
                    | (int(target_states[pin]) << 4)
                )

        if gp_settings[2] != self.pin_setting(sram, 2) or gp_settings[3] != self.pin_setting(sram, 3):
            self.set_sram_gpio_settings(gp_settings)

        self.set_gpio_outputs(target_states)
        return target_states

    def pulse_pin(
        self,
        pin: int,
        duration_seconds: float,
        active_state: bool = True,
    ) -> None:
        if duration_seconds <= 0:
            raise MCP2221Error("pulse duration must be greater than zero")

        inactive_state = not active_state
        self.ensure_pin_outputs({pin: inactive_state})
        self.set_gpio_outputs({pin: active_state})
        try:
            time.sleep(duration_seconds)
        finally:
            self.set_gpio_outputs({pin: inactive_state})

    def switch_status(self) -> dict[str, str]:
        sram = self.get_sram_settings()
        gpio = self.get_gpio_values()

        status: dict[str, str] = {}
        for name, pin in (("sd", PIN_SD_SWITCH), ("reset", PIN_RESET_SWITCH)):
            setting = self.pin_setting(sram, pin)
            designation = setting & 0x07
            direction = (setting >> 3) & 0x01

            if designation == GPIO_DESIGNATION_GPIO and direction == GPIO_DIRECTION_OUTPUT:
                value = gpio[2 + (pin * 2)]
                status[name] = (
                    sd_route_text(bool(value))
                    if pin == PIN_SD_SWITCH
                    else level_text(bool(value))
                )
            else:
                status[name] = f"not-gpio-output ({describe_pin_mode(setting)})"

        status["gp0"] = describe_pin_mode(self.pin_setting(sram, 0))
        status["gp1"] = describe_pin_mode(self.pin_setting(sram, 1))
        return status


def match_devices(
    devices: list[DeviceInfo],
    path: str | None,
    serial: str | None,
    vid: int | None,
    pid: int | None,
) -> list[DeviceInfo]:
    if path:
        return [device for device in devices if device.path == path]

    matches = devices
    if serial:
        matches = [device for device in matches if device.serial_number == serial]
    if vid is not None:
        matches = [device for device in matches if device.vendor_id == vid]
    if pid is not None:
        matches = [device for device in matches if device.product_id == pid]

    if serial or vid is not None or pid is not None:
        return matches

    preferred: list[DeviceInfo] = []
    for device in matches:
        manufacturer = device.manufacturer_string.lower()
        product = device.product_string.lower()
        if "mcp2221" in product or "microchip" in manufacturer:
            preferred.append(device)
    return preferred


def select_device(
    hidapi: HidApi,
    path: str | None,
    serial: str | None,
    vid: int | None,
    pid: int | None,
) -> DeviceInfo:
    matches = match_devices(hidapi.enumerate(), path, serial, vid, pid)
    if not matches:
        raise MCP2221Error("no matching MCP2221 HID device found; run `list` to inspect paths")
    if len(matches) > 1:
        details = "\n".join(
            f"  {device.path} serial={device.serial_number or '-'} "
            f"vid=0x{device.vendor_id:04x} pid=0x{device.product_id:04x}"
            for device in matches
        )
        raise MCP2221Error(
            "multiple matching HID devices found; rerun with --path or --serial:\n" + details
        )
    return matches[0]


def print_device_list(
    hidapi: HidApi,
    path: str | None,
    serial: str | None,
    vid: int | None,
    pid: int | None,
) -> int:
    devices = hidapi.enumerate()
    if path or serial or vid is not None or pid is not None:
        devices = match_devices(devices, path, serial, vid, pid)

    if not devices:
        print("No HID devices found.")
        return 1

    for device in devices:
        manufacturer = device.manufacturer_string or "-"
        product = device.product_string or "-"
        serial = device.serial_number or "-"
        print(
            f"path={device.path} vid=0x{device.vendor_id:04x} pid=0x{device.product_id:04x} "
            f"serial={serial} manufacturer={manufacturer!r} product={product!r}"
        )
    return 0


def add_selector_args(parser: argparse.ArgumentParser) -> None:
    parser.add_argument("--path", help="Open a specific HID device path.")
    parser.add_argument("--serial", help="Match a specific USB serial number.")
    parser.add_argument("--vid", type=parse_hex_int, help="Match a USB VID, for example 0x04d8.")
    parser.add_argument("--pid", type=parse_hex_int, help="Match a USB PID, for example 0x00dd.")


def command_state_to_bool(value: str) -> bool:
    if value == "on":
        return True
    if value == "off":
        return False
    raise ValueError(f"unsupported state {value}")


def sd_state_to_bool(value: str) -> bool:
    if value in {"reader", "on", "high"}:
        return SD_ROUTE_READER
    if value in {"device", "off", "low"}:
        return SD_ROUTE_DEVICE
    raise ValueError(f"unsupported SD route {value}")


def parse_pulse_seconds(value: str) -> float:
    seconds = float(value)
    if seconds <= 0:
        raise argparse.ArgumentTypeError("pulse duration must be greater than zero")
    return seconds


def build_parser() -> argparse.ArgumentParser:
    parser = argparse.ArgumentParser(
        description="Control GP2 (SD switch) and GP3 (reset pulse) on a MCP2221/MCP2221A."
    )
    subparsers = parser.add_subparsers(dest="command", required=True)

    list_parser = subparsers.add_parser("list", help="List HID devices visible through hidapi.")
    add_selector_args(list_parser)

    status_parser = subparsers.add_parser("status", help="Show current GP2/GP3 output state.")
    add_selector_args(status_parser)

    sd_parser = subparsers.add_parser(
        "sd",
        help="Route SD to the device or the SD card reader using GP2.",
    )
    sd_parser.add_argument(
        "state",
        choices=("device", "reader", "on", "off", "high", "low"),
        help="`reader`/`on`/`high` drives GP2 high. `device`/`off`/`low` drives GP2 low.",
    )
    add_selector_args(sd_parser)

    reset_parser = subparsers.add_parser(
        "reset",
        help="Pulse GP3 high, then return it low.",
    )
    reset_parser.add_argument(
        "--seconds",
        type=parse_pulse_seconds,
        default=0.1,
        help="Reset pulse width in seconds. Default: 0.1",
    )
    add_selector_args(reset_parser)

    return parser
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

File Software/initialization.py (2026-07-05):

#!/usr/bin/env python3
"""Program MCP2221 GP flash defaults for this fixture.

The MCP2221A can store GP pin configuration in flash. Those GP settings are copied
into SRAM on power-up/reset, which makes them the power-up defaults. This script
programs the fixture's intended defaults:

- GP0: LED_URX
- GP1: LED_UTX
- GP2: GPIO output high
- GP3: GPIO output low

The B-revision datasheet documents CHIPSETTING0 bits for the UART LED inactive
states, so this script also programs:

- LED_URX inactive low / active high
- LED_UTX inactive low / active high
"""

from __future__ import annotations

import argparse
import sys

from mcp2221_switch import (
    GPIO_DESIGNATION_ALT0,
    GPIO_DESIGNATION_ALT1,
    GPIO_DESIGNATION_GPIO,
    GPIO_DIRECTION_OUTPUT,
    HidApi,
    MCP2221,
    MCP2221Error,
    PIN_RESET_SWITCH,
    PIN_SD_SWITCH,
    PIN_UART_RX_LED,
    PIN_UART_TX_LED,
    SD_ROUTE_READER,
    add_selector_args,
    describe_pin_mode,
    encode_pin_setting,
    print_device_list,
    select_device,
)

CHIPSETTING0_LED_RX_INACTIVE_MASK = 1 << 6
CHIPSETTING0_LED_TX_INACTIVE_MASK = 1 << 5


def desired_gp_settings() -> list[int]:
    return [
        encode_pin_setting(GPIO_DESIGNATION_ALT0, GPIO_DIRECTION_OUTPUT, False),
        encode_pin_setting(GPIO_DESIGNATION_ALT1, GPIO_DIRECTION_OUTPUT, False),
        encode_pin_setting(GPIO_DESIGNATION_GPIO, GPIO_DIRECTION_OUTPUT, SD_ROUTE_READER),
        encode_pin_setting(GPIO_DESIGNATION_GPIO, GPIO_DIRECTION_OUTPUT, False),
    ]


def desired_flash_chip_settings(current_chip_settings: list[int] | bytes) -> list[int]:
    if len(current_chip_settings) != 4:
        raise ValueError("expected four chip settings bytes")
    updated = list(current_chip_settings)
    updated[0] &= ~(CHIPSETTING0_LED_RX_INACTIVE_MASK | CHIPSETTING0_LED_TX_INACTIVE_MASK)
    return updated


def led_polarity_text(chipsetting0: int, mask: int) -> str:
    if chipsetting0 & mask:
        return "inactive-high / active-low"
    return "inactive-low / active-high"


def print_chip_settings(label: str, chip_settings: list[int] | bytes) -> None:
    chipsetting0 = chip_settings[0]
    print(f"{label}:")
    print(f"  CHIPSETTING0: 0x{chipsetting0:02x}")
    print(f"  LED_URX polarity: {led_polarity_text(chipsetting0, CHIPSETTING0_LED_RX_INACTIVE_MASK)}")
    print(f"  LED_UTX polarity: {led_polarity_text(chipsetting0, CHIPSETTING0_LED_TX_INACTIVE_MASK)}")
    print(f"  raw bytes: {[f'0x{value:02x}' for value in chip_settings]}")


def describe_fixture_pin(pin: int, setting: int) -> str:
    if pin == PIN_UART_RX_LED and setting == encode_pin_setting(
        GPIO_DESIGNATION_ALT0, GPIO_DIRECTION_OUTPUT, False
    ):
        return "LED_URX"
    if pin == PIN_UART_TX_LED and setting == encode_pin_setting(
        GPIO_DESIGNATION_ALT1, GPIO_DIRECTION_OUTPUT, False
    ):
        return "LED_UTX"
    return describe_pin_mode(setting)


def print_settings(label: str, gp_settings: list[int] | bytes) -> None:
    print(f"{label}:")
    for pin, setting in enumerate(gp_settings):
        print(f"  GP{pin}: 0x{setting:02x} {describe_fixture_pin(pin, setting)}")


def build_parser() -> argparse.ArgumentParser:
    parser = argparse.ArgumentParser(
        description=(
            "Program MCP2221 flash GP defaults so GP2 powers up high, GP3 powers up low, "
            "and GP0/GP1 power up in UART LED modes."
        )
    )
    subparsers = parser.add_subparsers(dest="command", required=True)

    list_parser = subparsers.add_parser("list", help="List visible HID devices.")
    add_selector_args(list_parser)

    status_parser = subparsers.add_parser(
        "status",
        help="Show current flash and SRAM GP settings.",
    )
    add_selector_args(status_parser)

    reset_parser = subparsers.add_parser(
        "reset",
        help="Reset the MCP2221 so flash chip settings are reloaded from flash.",
    )
    add_selector_args(reset_parser)

    apply_parser = subparsers.add_parser(
        "apply",
        help="Write the desired power-up defaults to flash and apply them to SRAM now.",
    )
    apply_parser.add_argument(
        "--reset-chip",
        action="store_true",
        help="Reset the MCP2221 after writing flash so chip settings reload immediately.",
    )
    add_selector_args(apply_parser)
    return parser


def run(args: argparse.Namespace) -> int:
    hidapi = HidApi()
    try:
        if args.command == "list":
            return print_device_list(hidapi, args.path, args.serial, args.vid, args.pid)

        device = select_device(hidapi, args.path, args.serial, args.vid, args.pid)
        with MCP2221(hidapi, device.path) as mcp:
            if args.command == "reset":
                print(f"device: {device.path}")
                mcp.reset_chip()
                print("done: MCP2221 reset requested; it should re-enumerate on USB")
                return 0

            sram_response = mcp.get_sram_settings()
            flash_chip = list(mcp.get_flash_chip_settings())
            flash = list(mcp.get_flash_gpio_settings())
            sram_chip = list(sram_response[4:8])
            sram = [mcp.pin_setting(sram_response, pin) for pin in range(4)]

            if args.command == "status":
                print(f"device: {device.path}")
                print_chip_settings("flash chip settings", flash_chip)
                print_chip_settings("sram chip settings", sram_chip)
                print_settings("flash", flash)
                print_settings("sram", sram)
                print("note: LED polarity comes from flash CHIPSETTING0 and applies after reset/power-up.")
                return 0

            target = desired_gp_settings()
            target_chip = desired_flash_chip_settings(flash_chip)
            print(f"device: {device.path}")
            print_chip_settings("flash chip settings (before)", flash_chip)
            print_chip_settings("sram chip settings (before)", sram_chip)
            print_settings("flash (before)", flash)
            print_settings("sram (before)", sram)
            print_chip_settings("flash chip settings (target)", target_chip)
            print_settings("target", target)

            mcp.set_flash_chip_settings(target_chip)
            mcp.set_flash_gpio_settings(target)
            mcp.set_sram_gpio_settings(target)
            mcp.set_gpio_outputs(
                {
                    PIN_SD_SWITCH: SD_ROUTE_READER,
                    PIN_RESET_SWITCH: False,
                }
            )
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
